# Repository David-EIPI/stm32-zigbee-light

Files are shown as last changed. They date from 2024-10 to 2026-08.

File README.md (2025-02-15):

# stm32-zigbee-light
Remotely controlled deck light using a STM32WB55 and Homeassistant integration.

## Overview
This project is yet another automatic outdoor light. Some time back I have purchased a porch light with motion sensor, model 4190 by HeathZenith. My unit apparently was faulty, at least I could not make it to turn on and off at the right time. Instead of returning I have decided to turn it into a practice project to play with Zigbee and Homeassistant.

## Firmware
The firmware is written in C using STM32CubeIDE. I have preserved the link to the IOC file adding a few CPP macro hacks in the source.

The firmware implements 6 endpoints and 12 clusters:
- 6 Analog Output clusters
- 3 Binary Input clusters
- 1 Multistate Value cluster
- 1 Illuminance Measurement cluster
- 1 Temperature Measurement cluster

Zero crossing detection using STM32 timers is described in a [separate file](zerocrossing.md).

## Hardware
The replacement PCB board copies the shape of the original control board and fits in the same enclosure without modifications.

Also the switches, the pot, and the sensors are positioned to fit the holes in the enclosure and the outer case. The firmware reads the switches when not connected to the Zigbee network, otherwise remote settings take precedence.

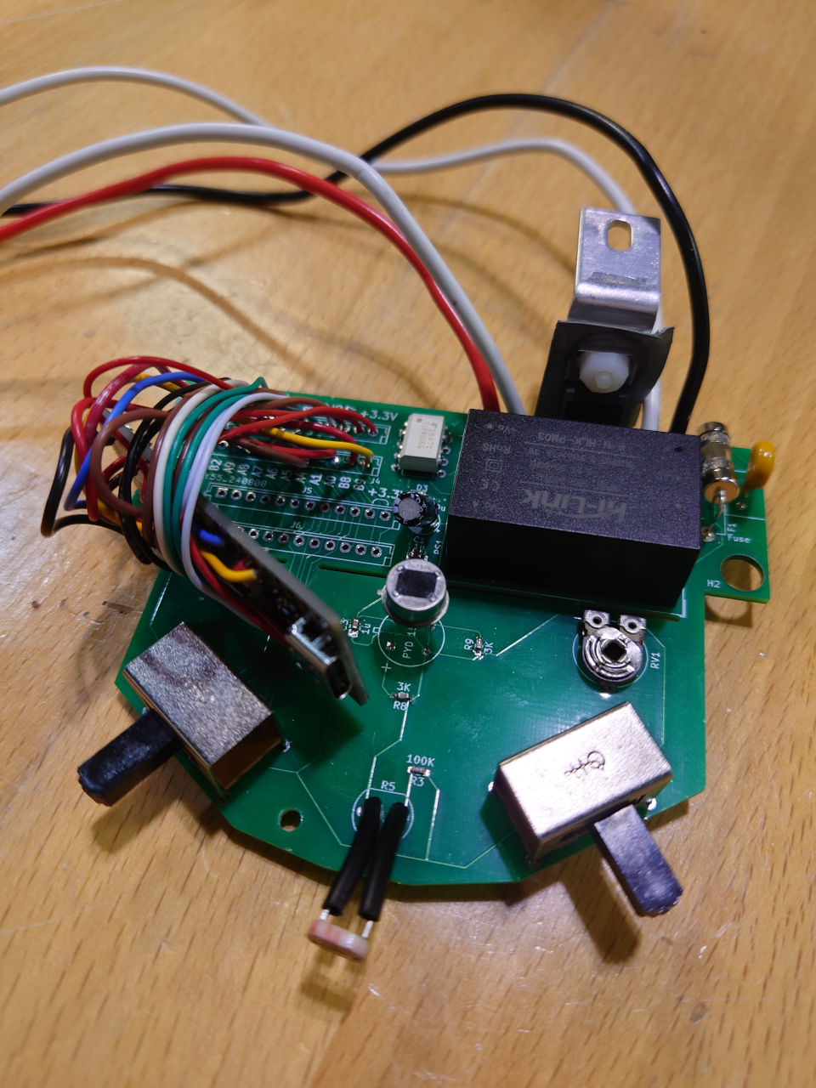
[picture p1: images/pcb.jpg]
The PCB, top view.


My setup uses STM32WB55 based board from WeAct, but any other 3.3V controller can be used.

The light is controlled with the triac dimmer triggered by the optocoupler. This configuration is only capable of leading-edge dimming, so a compatible bulb should be used. Phase adjustment (in ms) is needed to compensate for the zero-crossing detection circuit latency (mainly due to the optocoupler).

## ZHA quirck
Homeassistant's Zigbee integration recognizes most clusters from the firmware except the Multistate Value. The quirk file should be copied to the Homeassistant zha_quirk directory for proper work.

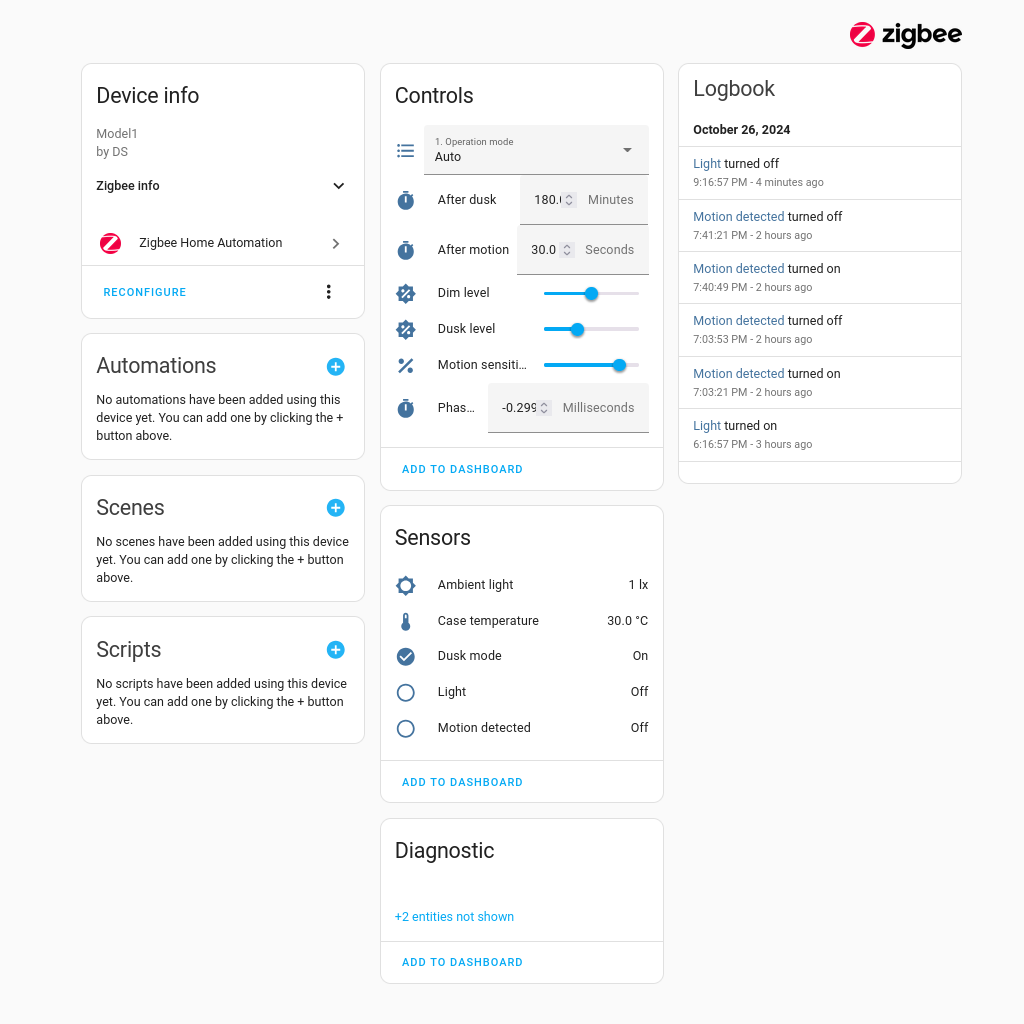
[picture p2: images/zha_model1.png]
Homeassistant device view

(I have edited the auto-generated entity labels visible in the screenshot.)

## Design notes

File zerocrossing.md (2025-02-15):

# Zero Crossing Detector

Many working detector schematics can be found on the internet. Here, I use a detector that likely has the simplest possible hardware implementation, with most of the work handled in software.

The following figure illustrates how this detector works:

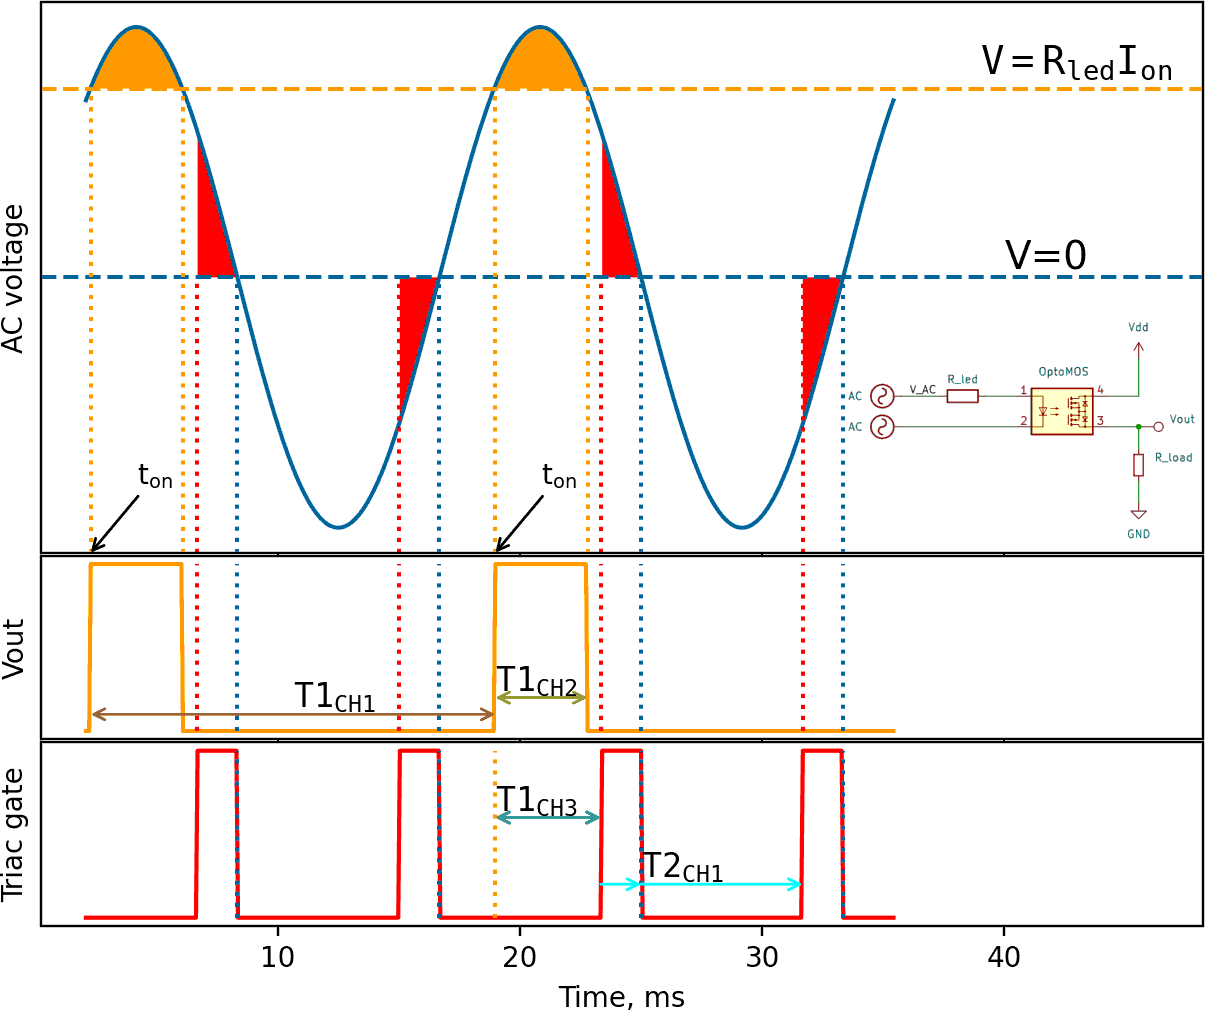
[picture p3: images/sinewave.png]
Zero crossing detector logic Fig 1. AC sine wave triggers the optocoupler. The digital output is converted using STM32 timers. The resulting PWM output drives the triac.

Fig 1. AC sine wave triggers the optocoupler. The digital output is converted using STM32 timers. The resulting PWM output drives the triac.

## The Circuit

The optocoupler turns on when the LED current reaches or exceeds its trigger current I<sub>on</sub> (orange lines in Fig 1). In my design, I use the TLP4006G, which has a typical I<sub>on</sub> = 1mA. The exact value of I<sub>on</sub> is not critical, nor is the value of the current-limiting resistor R<sub>led</sub>. The resistor simply needs to provide sufficient current to turn on the optocoupler without damaging it. For my design, intended for 120V mains, I chose R<sub>led</sub> = 80kΩ.

## The Timers

STM32 timers are configured to measure the resulting pulse length and period.

- **Timer 1, Channel 1** is configured in **Input Capture mode**. It is triggered by **TI1FP1** (PA8 on WB55) and resets on the rising edge of the same pin. The captured value stored in **TIM1_CCR1** represents the AC period.
  
- **Timer 1, Channel 2** is also configured in **Input Capture mode**, but in **Indirect mode**. It shares the input pin with **Channel 1** but is configured to reset on the **falling edge** of the optocoupler output. The captured value stored in **TIM1_CCR2** represents the output pulse length.

Knowing the AC period and optocoupler pulse duration allows us to calculate the zero-crossing moment:

t<sub>zc</sub> = t<sub>on</sub> + T1<sub>CH2</sub> / 2 + T1<sub>CH1</sub> / 4

Using this value, we can generate the correct TRIAC control waveform. Ideally, the TRIAC only requires a brief pulse to turn on and will stay on until the AC voltage crosses zero. However, extending the control pulse for the entire period the TRIAC needs to stay on improves output stability, especially for low-power loads like LED lights.

I use **2 additional timers** to generate the control pulses:

- **Timer 2, Channel 1** is set to **PWM mode** to generate pulses of the required duration. I set the period **TIM2_ARR** to match the AC wave half-period, as measured by **T1CH1**:

  T2<sub>ARR</sub> = T1<sub>CH1</sub> / 2

  The compare value **TIM2_CCR1** is determined by the desired duty cycle d &isin; [0, 1]:

  T2<sub>CCR1</sub> = d * T2<sub>ARR</sub>

- **Timer 1, Channel 3** is used to trigger **Timer 2**, which is configured to use ITR0. **T1CH3** runs in **PWM mode 2** and generates a trigger when the timer counter exceeds the compare value. The compare value **TIM1_CCR3** is set as shown in Fig 1 (dark green arrow): 

  T1<sub>CCR3</sub> = t<sub>zc</sub> - T2<sub>CCR1</sub>

  This trigger starts **Timer 2**, which generates a PWM output (red lines in Fig 1)   on **PA0 (WB55)**. This PWM output drives the second gate of the **TPL4006G** optocoupler, activating the TRIAC.

This 2 timer setup is required because TLP4006G can detect only positive half-period of the AC wave. With a bidirectional optocoupler it should be possible to configure **T1CH3** to output the TRIAC control pulses directly. With the unidirectional optocoupler a second auto-reloaded timer is required, which will run through the negative half-period without re-triggering.

### Automatic Operation
**Timer 2** registers do not need to be updated on every AC wave period. **T1CH1** and **T1CH2** automatically capture and store the AC wave period and the V<sub>out</sub> pulse duration. **T1CH3** and **T2CH1** are triggered automatically and generate PWM output without software intervention. Timers can be updated asynchronously within the sequencer loop; the new values will take effect on the next reload cycle.

## Phase Correction

The optocoupler introduces a noticeable switching delay that may affect TRIAC operation. For the **TPL4006G**, the on and off switching times are approximately **1ms**. To compensate for these delays, I introduced an adjustable phase correction time **t<sub>corr</sub>**, which is exposed as a setting. The corrected zero-crossing time is:

t<sub>zc</sub> = t<sub>on</sub> + T1<sub>CH2</sub> / 2 + T1<sub>CH1</sub> / 4 + t<sub>corr</sub>

### Determining t<sub>corr</sub>
I started with **t<sub>corr</sub> = 0** and adjusted it until my LED bulb reliably dimmed at a low PWM duty cycle **d = 10%**. For my circuit, I found **t<sub>corr</sub> &approx; 0.3ms**.

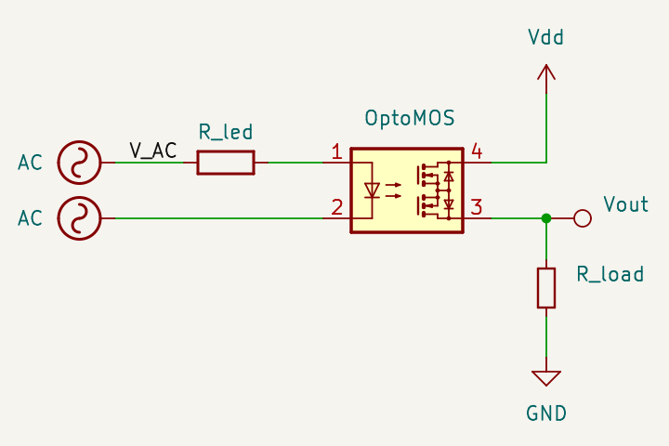
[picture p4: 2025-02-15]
images/ok_schematics.png

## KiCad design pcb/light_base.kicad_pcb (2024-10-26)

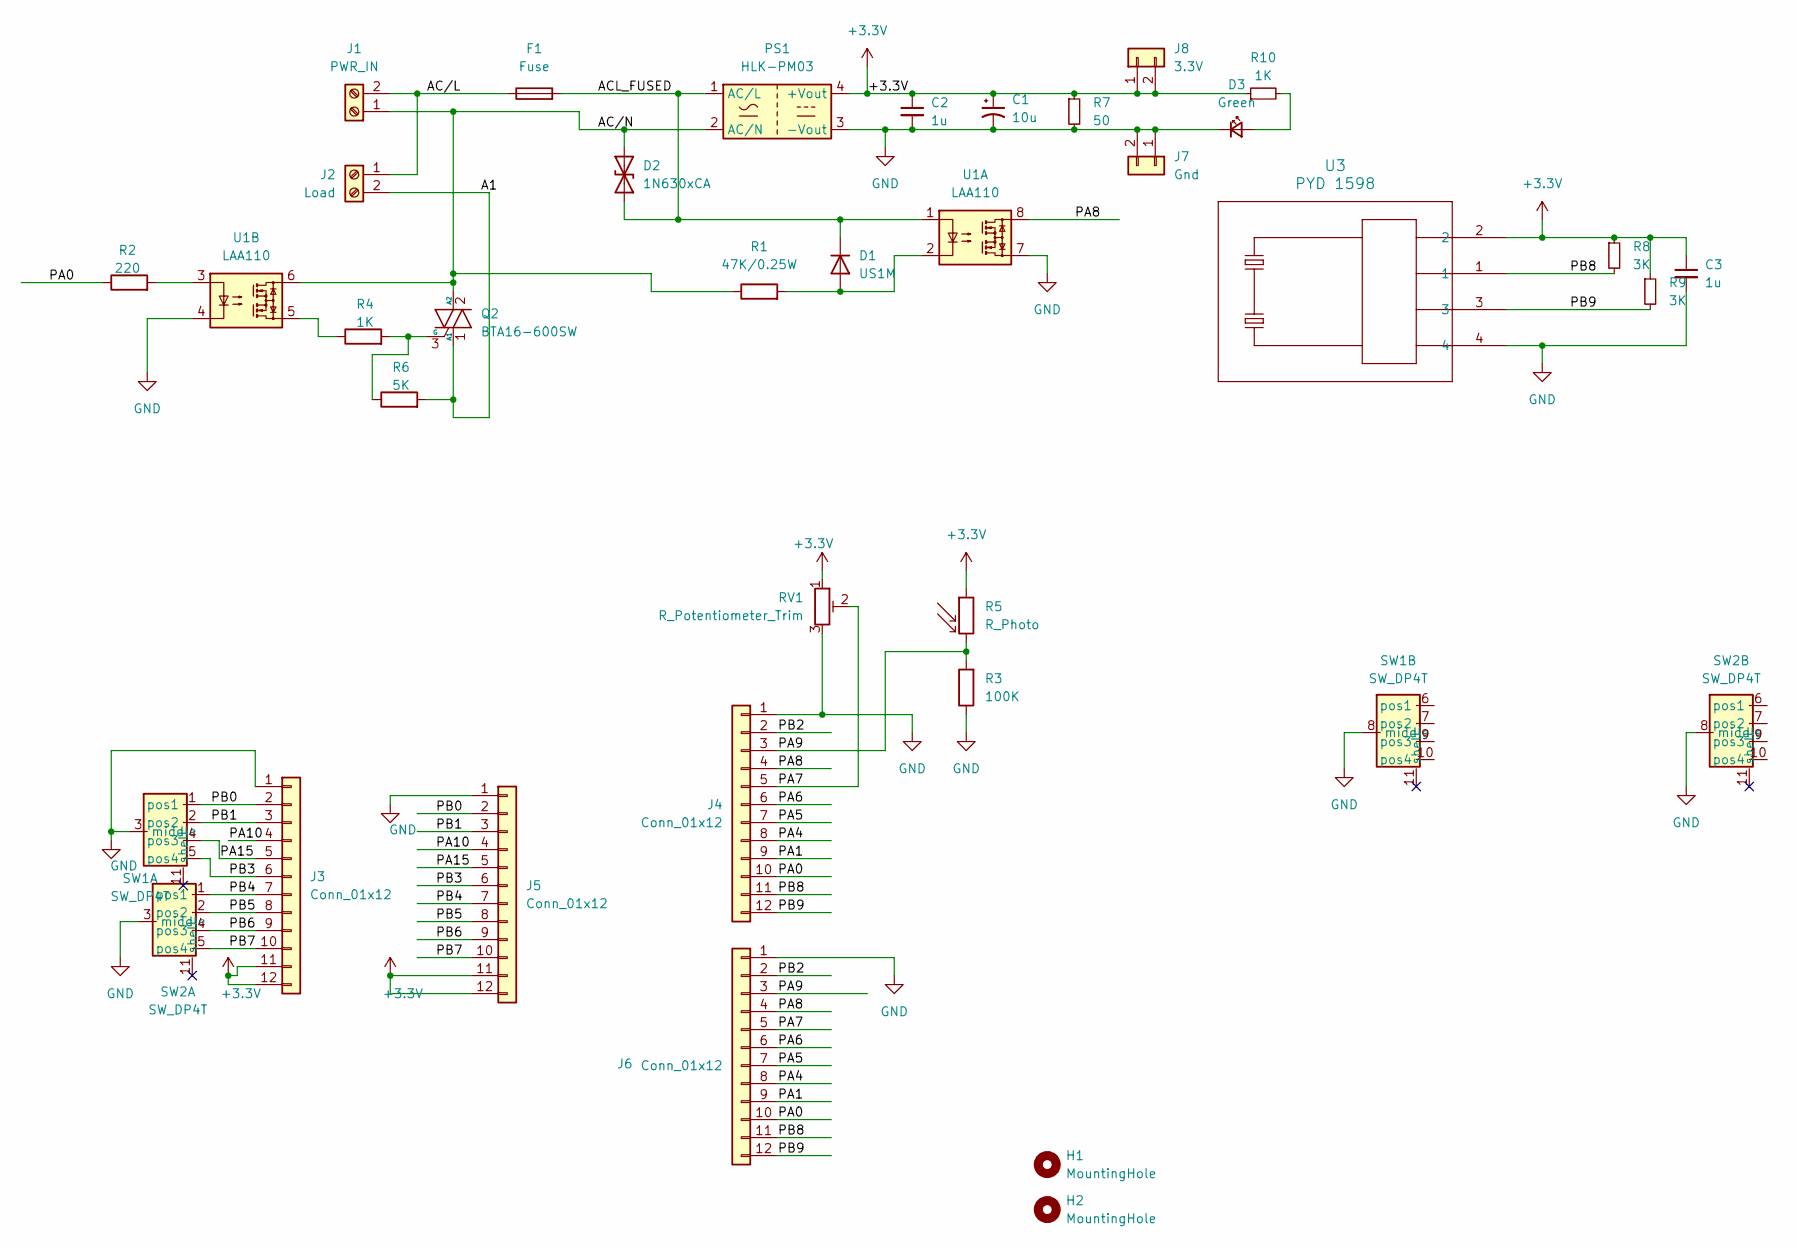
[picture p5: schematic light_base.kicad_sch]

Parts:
C1: 10u; CP_Radial_D5.0mm_P2.50mm
C2, C3: 1u; C_0805_2012Metric_Pad1.18x1.45mm_HandSolder
D1: US1M; D_SMA
D2: 1N630xCA; RV_Disc_D9mm_W6.1mm_P5mm
D3: Green; LED_0603_1608Metric_Pad1.05x0.95mm_HandSolder
F1: Fuse; R_Axial_DIN0614_L14.3mm_D5.7mm_P15.24mm_Horizontal
H1, H2: MountingHole; MountingHole_6.4mm_M6
J1: PWR_IN; JST_NV_B02P-NV_1x02_P5.00mm_Vertical
J2: Load; JST_NV_B02P-NV_1x02_P5.00mm_Vertical
J3, J4, J5, J6: Conn_01x12; JST_EH_B12B-EH-A_1x12_P2.50mm_Vertical
J7: Gnd; Molex_KK-254_AE-6410-02A_1x02_P2.54mm_Vertical
J8: 3.3V; Molex_KK-254_AE-6410-02A_1x02_P2.54mm_Vertical
PS1: HLK-PM03; Converter_ACDC_Hi-Link_HLK-PMxx
Q2: BTA16-600SW; TO-220-3_Vertical
R1: 47K/0.25W; R_1206_3216Metric_Pad1.30x1.75mm_HandSolder
R2: 220; R_0603_1608Metric_Pad0.98x0.95mm_HandSolder
R3: 100K; R_0603_1608Metric_Pad0.98x0.95mm_HandSolder
R4: 1K; R_1206_3216Metric_Pad1.30x1.75mm_HandSolder
R5: R_Photo; R_LDR_7x6mm_P5.1mm_Vertical
R6: 5K; R_1206_3216Metric_Pad1.30x1.75mm_HandSolder
R7: 50; R_0805_2012Metric_Pad1.20x1.40mm_HandSolder
R8, R9: 3K; R_0603_1608Metric_Pad0.98x0.95mm_HandSolder
R10: 1K; R_0603_1608Metric_Pad0.98x0.95mm_HandSolder
RV1: R_Potentiometer_Trim; Potentiometer_Piher_PT-10-V10_Vertical_Hole
SW1, SW2: SW_DP4T
U1: LAA110; DIP-8_W7.62mm
U3: PYD 1598; SENSE4_PYD 1598_EXT

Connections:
+3.3V: C1.1, C2.1, C3.1, J3.11, J3.12, J5.11, J5.12, J8.1, J8.2, PS1.4 (+Vout), R5.1, R7.1, R8.1, R9.1, R10.1, RV1.1, U3.2
/A1: J2.2, Q2.1 (A1), R6.2
/ACL_FUSED: D1.1 (K), D2.1 (A1), F1.2, PS1.1 (AC/L), U1.1
/AC/L: F1.1, J1.2, J2.1
/AC/N: D2.2 (A2), J1.1, PS1.2 (AC/N), Q2.2 (A2), R1.1, U1.6
/PA0: J4.10, J6.10, R2.1
/PA1: J4.9, J6.9
/PA4: J4.8, J6.8
/PA5: J4.7, J6.7
/PA6: J4.6, J6.6
/PA7: J4.5, J6.5, RV1.2
/PA8: J4.4, J6.4, U1.8
/PA9: J4.3, J6.3, R3.2, R5.2
/PA10: J3.4, J5.4
/PA15: J3.5, J5.5, SW1.4 (pos3)
/PB0: J3.2, J5.2, SW1.1 (pos1)
/PB1: J3.3, J5.3, SW1.2 (pos2)
/PB2: J4.2, J6.2
/PB3: J3.6, J5.6, SW1.5 (pos4)
/PB4: J3.7, J5.7, SW2.1 (pos1)
/PB5: J3.8, J5.8, SW2.2 (pos2)
/PB6: J3.9, J5.9, SW2.4 (pos3)
/PB7: J3.10, J5.10, SW2.5 (pos4)
/PB8: J4.11, J6.11, R8.2, U3.1
/PB9: J4.12, J6.12, R9.2, U3.3
GND: C1.2, C2.2, C3.2, D3.1 (K), J3.1, J4.1, J5.1, J6.1, J7.1, J7.2, PS1.3 (-Vout), R3.1, R7.2, RV1.3, SW1.3 (middle), SW1.8 (middle), SW2.3 (middle), SW2.8 (middle), U1.4, U1.7, U3.4
unnamed: D1.2 (A), R1.2, U1.2
unnamed: D3.2 (A), R10.2
unnamed: Q2.3 (G), R4.2, R6.1
unnamed: R2.2, U1.3
unnamed: R4.1, U1.5

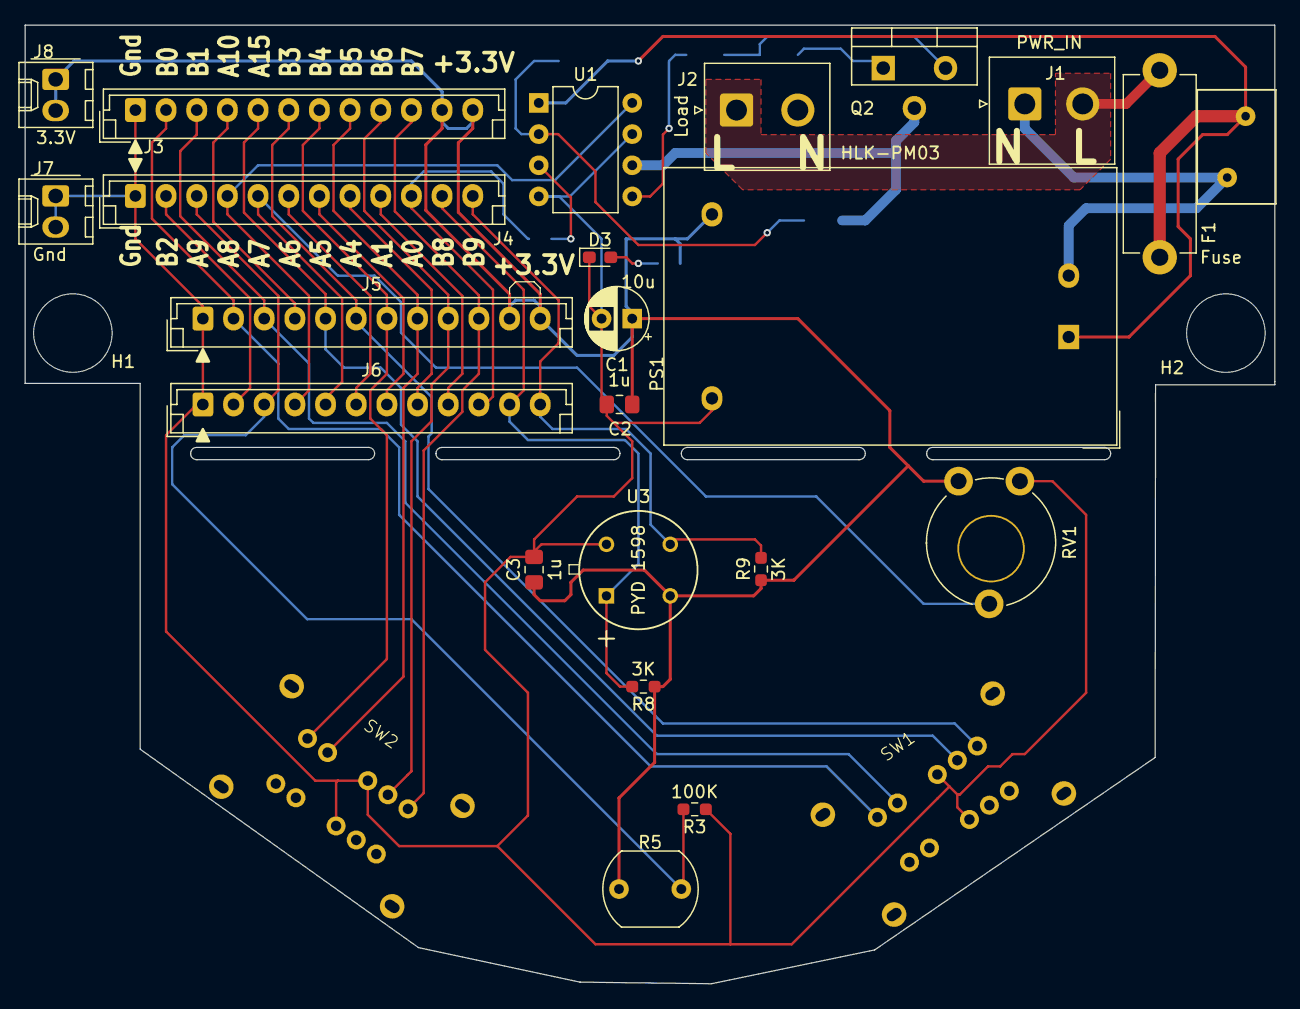
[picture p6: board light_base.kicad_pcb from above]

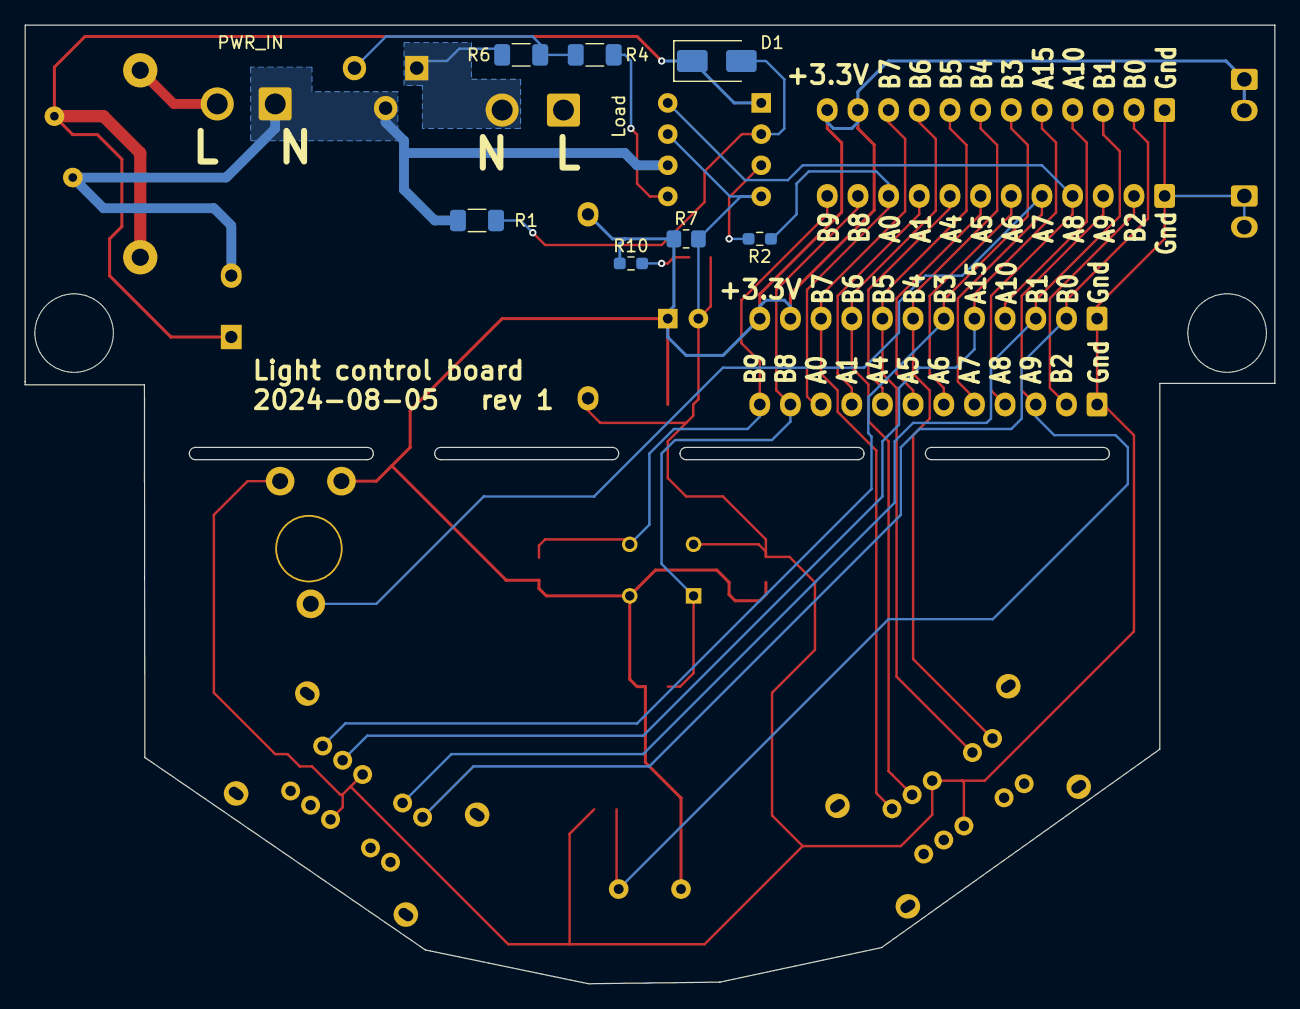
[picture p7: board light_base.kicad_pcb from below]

Board: 2 copper layers, 101.9 x 78.1 mm, 34 parts (7 on the bottom side), 31 nets.

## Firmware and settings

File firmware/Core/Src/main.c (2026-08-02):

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
/* Includes ------------------------------------------------------------------*/
#include "main.h"
#include "usb_device.h"

/* USER CODE BEGIN Includes */
#include "stm32_seq.h"
#include "usbd_cdc_if.h"
#include "stm_logging.h"
#include "dbg_trace.h"
#include "zigbee.h"
#include "app_zigbee.h"
#include "stm32wbxx_ll_tim.h"

#include "../../board/controls.h"

/* USER CODE END Includes */

/* USER CODE BEGIN PD */

/* Rough ambient light level correction for the self-illumination effect when the light is on */
#define CORRECT_SELF_ILLUM 3

/* Default values to use when not set remotely */
/* Range: 0-100 % */
#define DEFAULT_AMBIENT_THRESHOLD 50
#define DEFAULT_DIM_LEVEL 50

/* Optional last-resort periodic reset. Prefer the Zigbee recovery state machine
 * and watchdog; keep this disabled unless field experience shows it is useful. */
#define CFG_DAILY_RESTART 0

/* USER CODE END PD */

ADC_HandleTypeDef hadc1;
DMA_HandleTypeDef hdma_adc1;

IPCC_HandleTypeDef hipcc;

UART_HandleTypeDef hlpuart1;
DMA_HandleTypeDef hdma_lpuart1_tx;

RTC_HandleTypeDef hrtc;

TIM_HandleTypeDef htim16;

/* USER CODE BEGIN PV */
uint32_t usec_ticks;
uint32_t timeSeconds = 0;

/* time since dusk transition happened */
uint32_t duskTime = 0;

/* value of log2illum at which transition has happened (might not be equal to the ambientThreshold) */
uint32_t duskTransition = 0, dawnTransition = 0xffff;

/* Track illumination change */
int32_t prevIllum = 0;

/* Time when motion was last detected*/
uint32_t motionTime = 0;

/* Currently set light level in % */
uint8_t lightLevel = 0;

/* The last time the light was on */
uint32_t lightOnTime = 0;

/* Global settings */

/* light brightness when in manual mode, 1-100% */
int32_t dimLevel;

/* ambient light threshold, 0-100% */
int32_t ambientThreshold;

/* motion sensor sensitivity, 0-100% */
int32_t motionSensitivity;

/* time to keep the light on after motion detection, seconds */
int32_t motionLight;

/* time to keep dimmed light after dusk, minutes */
int32_t nightLight;

/* Light operation mode, values are from enum operationModes */
uint16_t operationMode = OP_AUTO;

/* Slide switch position settings. */
/* Full on time after motion detected */
static unsigned motion_light_switch[] = { // seconds
		0, 60, 300, 600
};

/* Dimmed time after dusk */
static unsigned night_light_switch[] = { // minutes
		0, 60*3, 60*6, 60*12,
};

/* Correction for the inaccuracy in phase detection, microseconds.
 * Mostly caused by the optocoupler latency.
 * Relative to 5000: values less then 5000 mean triac is triggered sooner, and above 5000 triac is triggered later.
 */
int32_t phase_correction = 0;

/* The triac on Model1 PCB only works with trailing edge control mode.
 * When using other control circuits trailing_edge can be set to 0 to use leading edge mode.
 *  */
uint8_t trailing_edge = USE_TRAILING_EDGE;

/* USER CODE END PV */

void SystemClock_Config(void);
void PeriphCommonClock_Config(void);
static void MX_GPIO_Init(void);
static void MX_DMA_Init(void);
static void MX_TIM17_Init(void);
static void MX_LPUART1_UART_Init(void);
static void MX_IPCC_Init(void);
static void MX_TIM1_Init(void);
static void MX_TIM2_Init(void);
static void MX_ADC1_Init(void);
static void MX_TIM16_Init(void);
static void MX_RTC_Init(void);
static void MX_RF_Init(void);
/* USER CODE BEGIN 0 */

void delay_us(uint16_t au16_us)
{
    LL_TIM_SetCounter(TIM16, 0);
    while (LL_TIM_GetCounter(TIM16) < au16_us);
}

void delay_ms(uint16_t au16_ms)
{
    while(au16_ms > 0)
    {
    	LL_TIM_SetCounter(TIM16, 0);
    	au16_ms--;
    	while (LL_TIM_GetCounter(TIM16) < 1000) {
    		;
    	}
    }
}

/*
 * Count seconds since start using the 16-bit timer with millisecond ticks
 * */
static uint16_t t17_prev = 0, t17_ms_accum = 0;
static void keep_time_seconds(void)
{
	uint16_t cnt = LL_TIM_GetCounter(TIM17) - t17_prev;
	t17_prev += cnt;
	cnt += t17_ms_accum;

	timeSeconds += cnt / 1000;
	t17_ms_accum = cnt % 1000;
}

int led_blink_count = 0;

/*
 * Use settings received remotely if connected to a network,
 * otherwise use settings from the local controls or defaults
 */
static
void check_and_update_settings(void)
{
	if (ZB_STATUS_SUCCESS == ZIGBEE_JoinStatus()) {
		update_motion_sensitivity(&motionSensitivity);
	} else {
		if (controls.slide_sw1 > 0 && controls.slide_sw1 <= lengthof(motion_light_switch))
			motionLight = motion_light_switch[controls.slide_sw1 - 1];

		if (controls.slide_sw2 > 0 && controls.slide_sw2 <= lengthof(motion_light_switch))
			nightLight = night_light_switch[controls.slide_sw2 - 1];

		ambientThreshold = DEFAULT_AMBIENT_THRESHOLD;
		dimLevel = DEFAULT_DIM_LEVEL;
		motion_send_configuration(controls.sensitivity);
	}
}

/* Auto select the light operation mode */
static
uint32_t auto_mode(void)
{
	uint32_t mode = OP_OFF;

	if (duskTime > 0 && timeSeconds < duskTime + abs(nightLight) * 60) {
		mode = OP_DIMMED;
	}

	if (duskTime > 0 && timeSeconds < motionTime + abs(motionLight)) {
		mode = OP_FULL;
	}
	return mode;
}

/* Apply light brightness level based on the current settings */
static
void check_and_update_light_level(void)
{
	uint32_t level = 100;
	uint32_t mode = operationMode;

	if (OP_AUTO == mode)
		mode = auto_mode();

	switch (mode) {
	case OP_AUTO:
		break;
	case OP_FULL:
		break;
	case OP_DIMMED:
		level = dimLevel;
		break;
	case OP_OFF:
		level = 0;
		break;
	default:
		return;
	}

	if (level != lightLevel)
		APP_ZIGBEE_update_lightstate(level > 0);

	lightLevel = level;

	if (level > 0)
		lightOnTime = timeSeconds;

	/* AC period */
	uint32_t pulse1 = LL_TIM_IC_GetCaptureCH1(TIM1);

	/* Duration of the detected pulse (sine top) */
	uint32_t pulse2 = LL_TIM_OC_GetCompareCH2(TIM1);

	LL_TIM_SetAutoReload(TIM2, pulse1 * usec_ticks / 2);

	uint32_t pwm_usec = (pulse1 * level) / 100 / 2;
	uint32_t zero_crossing_point = pulse2/2 + pulse1/4;

	if (trailing_edge)
		zero_crossing_point += pulse1 / 2 - pwm_usec;

	if (phase_correction > 0)
		zero_crossing_point += phase_correction;

	if (phase_correction < 0)
		zero_crossing_point -= abs(phase_correction);

	LL_TIM_OC_SetCompareCH3(TIM1, zero_crossing_point);

	uint32_t pwm_ticks = pwm_usec * usec_ticks;
	LL_TIM_OC_SetCompareCH1(TIM2, pwm_ticks);

}

/* Check the ambient light level to detect the dusk and the dawn */
static void detect_dusk_transition(void)
{
	int adjustedIllum = (int)controls.log2illum;

/* Roughly correct for self effect when the light is on and at least 1min after it was on till the sensor is settled */
	if (lightLevel > 0 || timeSeconds - abs(lightOnTime) < 60)
		adjustedIllum -= CORRECT_SELF_ILLUM;

	/* Dark to light transition: detect dawn */
	if ((duskTime > 0)
			&& (adjustedIllum > ambientThreshold)
			) {
		dawnTransition = prevIllum;
		duskTime = 0;
	}

	/* Light to dark transition: detect dusk */
	if ((duskTime == 0)
			&& (adjustedIllum < ambientThreshold)
			) {
		duskTransition = prevIllum;
		duskTime = timeSeconds;
	}
	prevIllum = adjustedIllum;
	APP_ZIGBEE_update_dusk_detect(duskTime > 0);
}

/* Variables needed to track the time */
static unsigned prevTime = 0;
static int prevTemp = 0;

/* Main application loop */
void seq_main_loop(void)
{
	keep_time_seconds();
	check_and_update_light_level();

/* Check interval is 1sec */
	if (timeSeconds > prevTime) {
		prevTime = timeSeconds;
		readBoardControls(&hadc1);

		APP_ZIGBEE_update_motion_detect(controls.motion);
		if (controls.motion)
			motionTime = timeSeconds;

		detect_dusk_transition();
		check_and_update_settings();

		if (prevTemp != controls.adc_temp) {
			prevTemp = controls.adc_temp;
			APP_ZIGBEE_update_temperature(controls.adc_temp);
		}
		APP_ZIGBEE_update_illum(controls.log2illum);
		APP_DBG("sw1: %d, sw2: %d, amb: %d, sen: %d raw: %d motion: %d \r",
				controls.slide_sw1, controls.slide_sw2, controls.log2illum, controls.sensitivity, controls.adc_voltage, controls.motion);
	}

	UTIL_SEQ_SetTask(1<< CFG_TASK_MAIN_LOOP, CFG_SCH_PRIO_1);
}

/* Setup daily restart */
void HAL_RTC_AlarmAEventCallback(RTC_HandleTypeDef *hrtc)
{
#if CFG_DAILY_RESTART
	HAL_NVIC_SystemReset();
#else
	UNUSED(hrtc);
#endif
}

#if CFG_DEBUG_TRACE
/* Debugging routine to direct the log output to the USB */
int _write(int file, char *ptr, int len) {
    static uint8_t rc = USBD_OK;

    do {
        rc = CDC_Transmit_FS((uint8_t *)ptr, len);
    } while (USBD_BUSY == rc);

    if (USBD_FAIL == rc) {
        /// NOTE: Should never reach here.
        /// TODO: Handle this error.
        return 0;
    }
    return len;
}
#endif

/* Apply the motion sensitivity setting when requested via the network */
void update_motion_sensitivity(int32_t *value)
{
	/* Value is ranged 0-100%, convert it to the proper range for controls and call the update function. */
	uint8_t threshold = ((100 - motionSensitivity) * 255) / 100;
	if (threshold > 255) threshold = 255;
	motion_send_configuration(threshold);
}

/* USER CODE END 0 */

/**
  * @brief  The application entry point.
  * @retval int
  */
int main(void)
{

  /* MCU Configuration--------------------------------------------------------*/

  /* Reset of all peripherals, Initializes the Flash interface and the Systick. */
  HAL_Init();
  /* Config code for STM32_WPAN (HSE Tuning must be done before system clock configuration) */
  MX_APPE_Config();

  /* Configure the system clock */
  SystemClock_Config();

/* Configure the peripherals common clocks */
  PeriphCommonClock_Config();

  /* IPCC initialisation */
  MX_IPCC_Init();

  /* Initialize all configured peripherals */
  MX_GPIO_Init();
  MX_DMA_Init();
  MX_USB_Device_Init();
  MX_TIM17_Init();
  MX_LPUART1_UART_Init();
  MX_TIM1_Init();
  MX_TIM2_Init();
  MX_ADC1_Init();
  MX_TIM16_Init();
  MX_RTC_Init();
  MX_RF_Init();
  /* USER CODE BEGIN 2 */
  HAL_ADCEx_Calibration_Start(&hadc1, ADC_SINGLE_ENDED);


  /* D.Sh. Crucial to prevent CPU2 from corrupting USB clock.
 * Credit: https://community.st.com/t5/stm32-mcus-wireless/usb-device-does-not-work-when-starting-ble-stack-on-stm32wb55/m-p/176360 */
//  LL_HSEM_1StepLock(HSEM, 5);
/* A more detailed code is in  PeriphCommonClock_Config*/


  LL_TIM_CC_EnableChannel(TIM1, LL_TIM_CHANNEL_CH1 | LL_TIM_CHANNEL_CH2 | LL_TIM_CHANNEL_CH3);
  LL_TIM_EnableCounter(TIM1);

  LL_TIM_CC_EnableChannel(TIM2, LL_TIM_CHANNEL_CH1);
  LL_TIM_EnableCounter(TIM2);
  LL_TIM_CC_EnableChannel(TIM17, LL_TIM_CHANNEL_CH1 );
  LL_TIM_EnableCounter(TIM17);
  LL_TIM_CC_EnableChannel(TIM16, LL_TIM_CHANNEL_CH1 );
  LL_TIM_EnableCounter(TIM16);

//  motion_send_configuration(&motionSensitivity);

  /* USER CODE END 2 */

  /* Init code for STM32_WPAN */
  MX_APPE_Init();

  /* Infinite loop */
  /* USER CODE BEGIN WHILE */
  UTIL_SEQ_RegTask(1<< CFG_TASK_MAIN_LOOP, UTIL_SEQ_RFU, seq_main_loop);
  UTIL_SEQ_SetTask(1<< CFG_TASK_MAIN_LOOP, CFG_SCH_PRIO_1);
  APP_DBG("Test debug output\n");

  while (1)
  {
    /* USER CODE END WHILE */
    MX_APPE_Process();

    /* USER CODE BEGIN 3 */
  }
  /* USER CODE END 3 */
}

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
/* USER CODE BEGIN 4 */

#if CFG_DAILY_RESTART
void RTC_Alarm_IRQHandler(void)
{
	HAL_RTC_AlarmIRQHandler(&hrtc);
}
#endif

/* USER CODE END 4 */
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


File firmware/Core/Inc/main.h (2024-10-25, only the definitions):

#define DLINK_Pin LL_GPIO_PIN_8
#define DLINK_GPIO_Port GPIOB
#define SERIN_Pin LL_GPIO_PIN_9
#define SERIN_GPIO_Port GPIOB
#define TRIAC_CTRL_Pin LL_GPIO_PIN_0
#define TRIAC_CTRL_GPIO_Port GPIOA
#define ZERO_CROSS_Pin LL_GPIO_PIN_8
#define ZERO_CROSS_GPIO_Port GPIOA
#define SW1_P1_Pin LL_GPIO_PIN_0
#define SW1_P1_GPIO_Port GPIOB
#define SW1_P2_Pin LL_GPIO_PIN_1
#define SW1_P2_GPIO_Port GPIOB
#define BOARDLED_Pin LL_GPIO_PIN_4
#define BOARDLED_GPIO_Port GPIOE
#define SW1_P4_Pin LL_GPIO_PIN_15
#define SW1_P4_GPIO_Port GPIOA
#define SW1_P5_Pin LL_GPIO_PIN_3
#define SW1_P5_GPIO_Port GPIOB
#define SW2_P1_Pin LL_GPIO_PIN_4
#define SW2_P1_GPIO_Port GPIOB
#define SW2_P2_Pin LL_GPIO_PIN_5
#define SW2_P2_GPIO_Port GPIOB
#define SW2_P4_Pin LL_GPIO_PIN_6
#define SW2_P4_GPIO_Port GPIOB
#define SW2_P5_Pin LL_GPIO_PIN_7
#define SW2_P5_GPIO_Port GPIOB

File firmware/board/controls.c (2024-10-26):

/**
  ******************************************************************************
  * @file           : controls.c
  * @author         : David Shirvanyants
  * @date           : Aug 31, 2024
  * @brief          : Hardware interface data, functions and drivers.
  ******************************************************************************
  * @attention
  *
  * This software is licensed under terms that can be found in the LICENSE file
  * in the root directory of this software component.
  * If no LICENSE file comes with this software, it is provided AS-IS.
  *
  ******************************************************************************
  */
#include <math.h>

#include "controls.h"
#include "limits.h"
#include "main.h"

#define LOW_PASS_BITS 7

#define ADC_LOW_PASS 128 // a coefficient in AMBIENT_RANGE

#define AVG_SLOPE (430)
#define V_AT_25C  (164)
#define V_REF_INT (1210)

struct controlsRec controls = { 0 };


/* Slide switches */
static uint32_t switch1_gpio_pin[] = {
		SW1_P1_Pin,
		SW1_P2_Pin,
		SW1_P4_Pin,
		SW1_P5_Pin,
};

static GPIO_TypeDef * switch1_gpio_port[] = {
		SW1_P1_GPIO_Port,
		SW1_P2_GPIO_Port,
		SW1_P4_GPIO_Port,
		SW1_P5_GPIO_Port,
};

static uint32_t switch2_gpio_pin[] = {
		SW2_P1_Pin,
		SW2_P2_Pin,
		SW2_P4_Pin,
		SW2_P5_Pin,
};

static GPIO_TypeDef * switch2_gpio_port[] = {
		SW2_P1_GPIO_Port,
		SW2_P2_GPIO_Port,
		SW2_P4_GPIO_Port,
		SW2_P5_GPIO_Port,
};


static uint32_t sw1_states[lengthof(switch1_gpio_pin)] = { 0 };
static uint32_t sw2_states[lengthof(switch1_gpio_pin)] = { 0 };

/*
 * @var Analog inputs: ambient light, sensitivity pot
 *      and on-chip voltage and temperature sensors
 *  */
volatile uint16_t adcdmavals[4] = {0};

static int adc_updated = 1;

enum {
	ADC_SLOT_LDR = 0,
	ADC_SLOT_POT = 1,
	ADC_SLOT_TEMP = 2,
	ADC_SLOT_VREF = 3,
};

/*
 * @var Motion sensor data register
 * */
unsigned dl_data[2] = { 0 };
unsigned motion_sensor_dl_cnt = 0;

/*
 * @var Motion sensor configuration register
 * */
union {
	struct {
		unsigned count_mode:1;      // count with (0) or without (1) BPF sign change
		unsigned reserved2:1;       // Reserved: Must be set to dec 0
		unsigned hpf_cut_off:1;     // 0: 0.4 Hz 1: 0.2 Hz
		unsigned reserved1:2;       // Reserved: Must be set to dec 2
		unsigned signal_source:2;   // 0: PIR (BPF) 1: PIR (LPF) 2: Reserved 3: Temperature Sensor
		unsigned operation_mode:2;  // 0: Forced Readout 1: Interrupt Readout 2: Wake Up 3: Reserved
		unsigned window_time:2;     // = 2 s + [Reg Val] · 2 s
		unsigned pulse_counter:2;   // = 1 + [Reg Val]
		unsigned blind_time:4;      // = 0.5 s + [Reg Val] · 0.5 s
		unsigned threshold:8;       // Detection threshold on BPF value
	};
	unsigned bits;
} config_register = {
		.count_mode = 0,
		.reserved2 = 0,
		.hpf_cut_off = 0,
		.reserved1 = 2,
		.signal_source = 0,
		.operation_mode = 2,
		.window_time = 0,
		.pulse_counter = 0,
		.blind_time = 0,
		.threshold = 200,
};



LL_GPIO_InitTypeDef init_input = {
		  .Pin = DLINK_Pin,
		  .Mode = LL_GPIO_MODE_INPUT,
		  .Pull = LL_GPIO_PULL_NO,
};

LL_GPIO_InitTypeDef init_output = {
		  .Pin = DLINK_Pin,
		  .Mode = LL_GPIO_MODE_OUTPUT,
		  .OutputType = LL_GPIO_OUTPUT_PUSHPULL,
		  .Pull = LL_GPIO_PULL_NO,
		  .Speed = LL_GPIO_SPEED_FREQ_HIGH,
};


/*
 * @brief Read PYD1588 data bytes.
 *        Here we do not use this data, but reading it resets the DIRECT LINE pin.
 *        This pin is set high upon positive motion detection and is not reset automatically.
 * */
void read_dl_data(void)
{
	dl_data[0] = 0;
	dl_data[1] = 0;

	LL_GPIO_SetOutputPin(DLINK_GPIO_Port, DLINK_Pin);

	LL_GPIO_Init(DLINK_GPIO_Port, &init_output);
	LL_GPIO_SetPinSpeed(DLINK_GPIO_Port, DLINK_Pin, LL_GPIO_SPEED_FREQ_HIGH);
	delay_us(120); // forced pulse

	int i;
	for (i = 0; i < 15; i++) {
		LL_GPIO_ResetOutputPin(DLINK_GPIO_Port, DLINK_Pin);
		delay_us(1);
		LL_GPIO_SetOutputPin(DLINK_GPIO_Port, DLINK_Pin);
		delay_us(1);
		LL_GPIO_SetPinMode(DLINK_GPIO_Port, DLINK_Pin, LL_GPIO_MODE_INPUT);
		delay_us(5);
		int bit = LL_GPIO_IsInputPinSet(DLINK_GPIO_Port, DLINK_Pin);
		dl_data[1] = (dl_data[1] << 1) | bit;
		LL_GPIO_SetPinMode(DLINK_GPIO_Port, DLINK_Pin, LL_GPIO_MODE_OUTPUT);
		LL_GPIO_SetPinSpeed(DLINK_GPIO_Port, DLINK_Pin, LL_GPIO_SPEED_FREQ_HIGH);
	}
	for (i = 0; i < 25; i++) {
		LL_GPIO_ResetOutputPin(DLINK_GPIO_Port, DLINK_Pin);
		delay_us(1);
		LL_GPIO_SetOutputPin(DLINK_GPIO_Port, DLINK_Pin);
		delay_us(1);
		LL_GPIO_SetPinMode(DLINK_GPIO_Port, DLINK_Pin, LL_GPIO_MODE_INPUT);
		delay_us(5);
		int bit = LL_GPIO_IsInputPinSet(DLINK_GPIO_Port, DLINK_Pin);
		dl_data[0] = (dl_data[0] << 1) | bit;
		LL_GPIO_SetPinMode(DLINK_GPIO_Port, DLINK_Pin, LL_GPIO_MODE_OUTPUT);
		LL_GPIO_SetPinSpeed(DLINK_GPIO_Port, DLINK_Pin, LL_GPIO_SPEED_FREQ_HIGH);
	}
	LL_GPIO_ResetOutputPin(DLINK_GPIO_Port, DLINK_Pin);
	delay_us(1250); // end
	LL_GPIO_Init(DLINK_GPIO_Port, &init_input);
}

/*
 * @brief Update the PYD1588 configuration.
 *        This transmits the configuration register contents
 *        including the possibly updated motion detection threshold.
 * */
void motion_send_configuration(uint8_t threshold)
{
	config_register.threshold = threshold;

	int mask = (1 << 24);

	int i;
	for (i = 0; i < 25; i++) {
		LL_GPIO_SetOutputPin(SERIN_GPIO_Port, SERIN_Pin);

		if (((config_register.bits & mask) != 0))
			LL_GPIO_SetOutputPin(SERIN_GPIO_Port, SERIN_Pin);
		else
			LL_GPIO_ResetOutputPin(SERIN_GPIO_Port, SERIN_Pin);

		delay_us(80);
		LL_GPIO_ResetOutputPin(SERIN_GPIO_Port, SERIN_Pin);
		mask >>= 1;
	}
}


/*
 * @brief Integer low-pass filter with (1 << LOW_PASS_BITS) transition steps.
 * */
uint32_t inputLowPassFilter(uint32_t current, uint32_t newval)
{
	unsigned result = current;
	if (result > 0) result -= 1;
	result += 2 * (!!newval);
	result &= (1 << LOW_PASS_BITS) - 1;
	return result;
}

/*
 * @brief Schmitt trigger at 1/4 and 3/4 thresholds.
 * */
uint32_t inputSchmittTrigger(unsigned oldval, unsigned level)
{
	unsigned result = oldval;
	if ((result != 0) && (level < (1 << LOW_PASS_BITS)/4) ) {
		result = 0;
	}
	if ((result == 0) && (level > (1 << LOW_PASS_BITS) - (1 << LOW_PASS_BITS)/4) ) {
		result = 1;
	}
	return result;
}

/*
 * a[n] = 40 * log2(n)
 * This will be divided by 30 at runtime, 30/40 = 0.75 = k = photoresistor constant
 */
static unsigned log_table[16] = {
		0, 0, 40, 63, 80, 93, 103, 112, 120, 127, 133, 138, 143, 148, 152, 156
};

static int32_t ambientSensor = 0;

static void read_temperature(void)
{
	int vref = (V_REF_INT * 4095) / adcdmavals[ADC_SLOT_VREF];
//	int vsense = (vref * adcdmavals[2]) / 4095;
//	int tC = ((V_AT_25C - vsense) * 1000) / (AVG_SLOPE/10) + 250;
	int tC = 100* __LL_ADC_CALC_TEMPERATURE(vref, adcdmavals[ADC_SLOT_TEMP], LL_ADC_RESOLUTION_12B);
	controls.adc_temp = tC;
}
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

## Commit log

2024-10-26 Add PCB design files
    [light_base.kicad_pcb, light_base.kicad_sch]
2025-03-14 Changes related to Zigbee connectivity.
    Remove NwkRejoin code - M0 FW seems to handle leave-rejoin well.
    Increase TX Power.
    Remove cost threshold for parent connection.
    Reduce persistense frequency.
2025-03-16 Switch Zigbee device type to router. This seems to result in a more stable connection.
    Change Phase Correction units to microseconds. Add support for
    microseconds to ZHA using quirk file.
    Remove some unused code.
    [app_conf.h, app_zigbee.c, main.c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]
2026-08-02 Correctly set BDB flags
    [app_zigbee.c]
2026-08-02 Fix possible cause for intermittent network loss
    The controller occasionally disconnects from the network
    and never returns until erased and re-flashed. Hoping to fix this
    issue I have run Codex/ChatGPT5.6 code diagnostics. It suggested
    that the most likely cause of the annoying disconnections
    is rooted in the process of restoring the connection from the
    saved persistence. The opaque firmware on CPU2 handles
    connection from persistence asynchronously. When started,
    it immediately returs success before it succesfully joins
    the network. If persistence data is somehow damaged
    CPU2 may never join the network, and main firmware on CPU1
    will never notice that as it never checks connection state
    af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
    [app_conf.h, app_zigbee.c, main.c]

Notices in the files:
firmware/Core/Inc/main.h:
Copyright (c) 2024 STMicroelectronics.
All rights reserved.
